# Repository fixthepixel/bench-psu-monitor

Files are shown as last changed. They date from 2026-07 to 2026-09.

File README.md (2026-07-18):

# Bench PSU Monitor

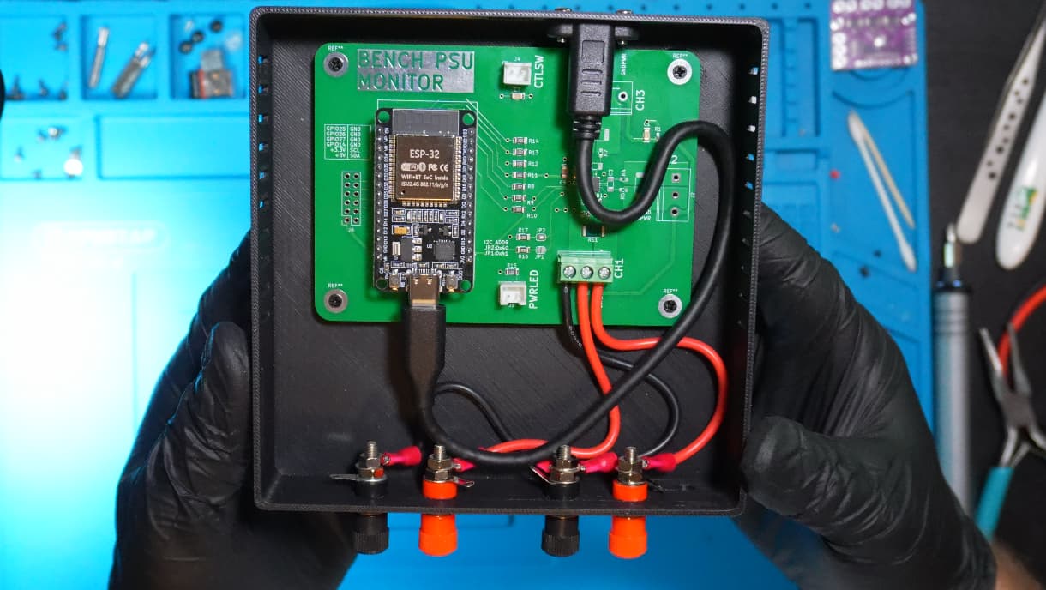
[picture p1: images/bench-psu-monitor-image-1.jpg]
Board


A 3-channel bench power supply monitor PCB built around an **ESP32 DevKit V1** and a **Texas Instruments INA3221** triple-channel current/voltage sense IC.

## Features

- 3 independent measurement channels (CH1, CH2, CH3) via screw terminals
- Voltage and current monitoring over I²C using the INA3221
- 10 mΩ shunt resistors for current sensing
- I²C address selection via solder jumpers JP1/JP2
- Compact 2-layer PCB with gerbers ready for fabrication

## Interactive BOM

[View Interactive BOM](https://fixthepixel.github.io/bench-psu-monitor/bom/ibom.html)

## Hardware

| Component | Value / Part |
|---|---|
| MCU | ESP32 DevKit V1 (30-pin) |
| Current/Voltage monitor | INA3221 (3-channel, I²C) |
| Shunt resistors | 10 mΩ (RS1, RS2, RS3) |
| Bypass capacitor | 100 nF |
| Bulk capacitor | 10 µF |

## Repository Contents

```
bench-psu-monitor.kicad_sch   Schematic
bench-psu-monitor.kicad_pcb   PCB layout
bom/ibom.html                 Interactive BOM
gerber/                       Gerber files for fabrication
firmware/                     ESP32 Arduino sketch
```

See [firmware/README.md](firmware/README.md) for flashing instructions, library dependencies, and WebSocket API reference.

## Fabrication

Gerber files are in [gerber/](gerber/) and can be sent directly to any PCB manufacturer. The board is 2-layer (F_Cu / B_Cu).

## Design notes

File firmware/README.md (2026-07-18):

# Firmware — Bench PSU Monitor

Arduino sketch for the ESP32-based bench power supply monitor. Reads voltage, current, and power from an INA3221 and streams the data over WebSocket at 10 Hz.

## Requirements

### Hardware

| Component | Detail |
|---|---|
| MCU | ESP32 DevKit V1 |
| Sensor | INA3221 at I²C address `0x40` |
| Shunt (CH1) | 10 mΩ (`SHUNT_R_CH1 = 0.01`) |
| Calibration button | GPIO0 (BOOT button) |
| WiFi button | GPIO23 |

### Libraries

Install via Arduino Library Manager or the links below:

| Library | Purpose |
|---|---|
| [Adafruit INA3221](https://github.com/adafruit/Adafruit_INA3221) | INA3221 driver |
| [WiFiManager](https://github.com/tzapu/WiFiManager) | Captive-portal WiFi setup |
| [ESPAsyncWebServer](https://github.com/me-no-dev/ESPAsyncWebServer) | Async HTTP + WebSocket server |
| [AsyncTCP](https://github.com/me-no-dev/AsyncTCP) | Async TCP layer (ESPAsyncWebServer dependency) |

`Wire.h`, `WiFi.h`, and `Preferences.h` are bundled with the ESP32 Arduino core.

### Arduino IDE Setup

1. Add the ESP32 board package URL in **File → Preferences → Additional Boards Manager URLs**:
   ```
   https://raw.githubusercontent.com/espressif/arduino-esp32/gh-pages/package_esp32_index.json
   ```
2. Install **esp32 by Espressif** via **Tools → Board → Boards Manager**.
3. Select **ESP32 Dev Module** as the target board.

## Flashing

1. Open `bench-psu-monitor.ino` in Arduino IDE.
2. Connect the ESP32 via USB.
3. Select the correct COM port under **Tools → Port**.
4. Click **Upload**.

## First-Time WiFi Configuration

On first boot (or after a reset), the device will not be connected to WiFi. Hold **GPIO23** for **3 seconds** to launch the captive-portal access point (`INA3221-Setup`). Connect to that AP from a phone or laptop, enter your WiFi credentials, and the device will save them to flash and reboot.

## Calibration

Zero-offset calibration compensates for shunt resistor and board offsets at no-load:

1. Disconnect all load from CH1.
2. Hold the **BOOT button (GPIO0)** for **2 seconds**.
3. The offset is measured and stored in NVS (survives reboots).

## WebSocket Data

Once connected to WiFi, the device hosts a WebSocket endpoint:

```
ws://<device-ip>/ws
```

JSON frames are broadcast at **100 ms intervals** (10 Hz):

```json
{"v": 12.345, "i": 123.45, "p": 1523.4, "ts": 12345678}
```

| Key | Unit | Description |
|-----|---|---|
| `v` | V | Bus voltage |
| `i` | mA | Current (zero-offset corrected) |
| `p` | mW | Power |
| `ts` | ms | `millis()` timestamp |

## Pin Summary

| GPIO | Function |
|---|---|
| 21 | I²C SDA |
| 22 | I²C SCL |
| 0 | Zero calibration (hold 2 s) |
| 23 | WiFi config portal (hold 3 s) |

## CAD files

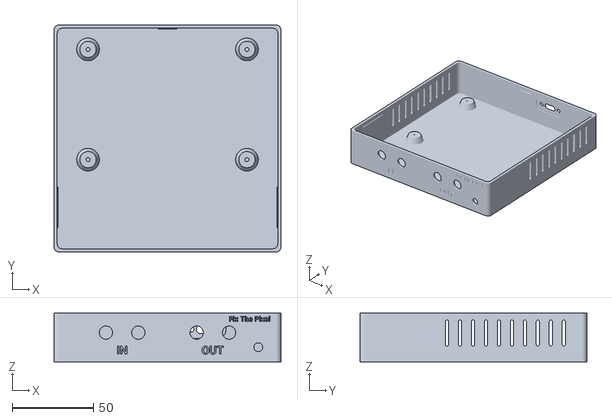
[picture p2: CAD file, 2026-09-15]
enclosure/PSU_Monitor_Enclosure.stl
140.0 x 140.0 x 30.0

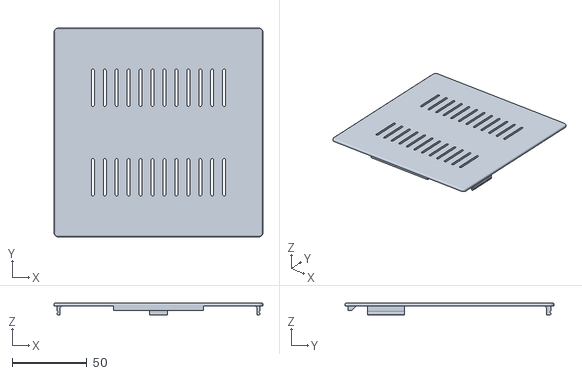
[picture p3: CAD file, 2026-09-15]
enclosure/PSU_Monitor_Lid.stl
140.0 x 140.0 x 8.00

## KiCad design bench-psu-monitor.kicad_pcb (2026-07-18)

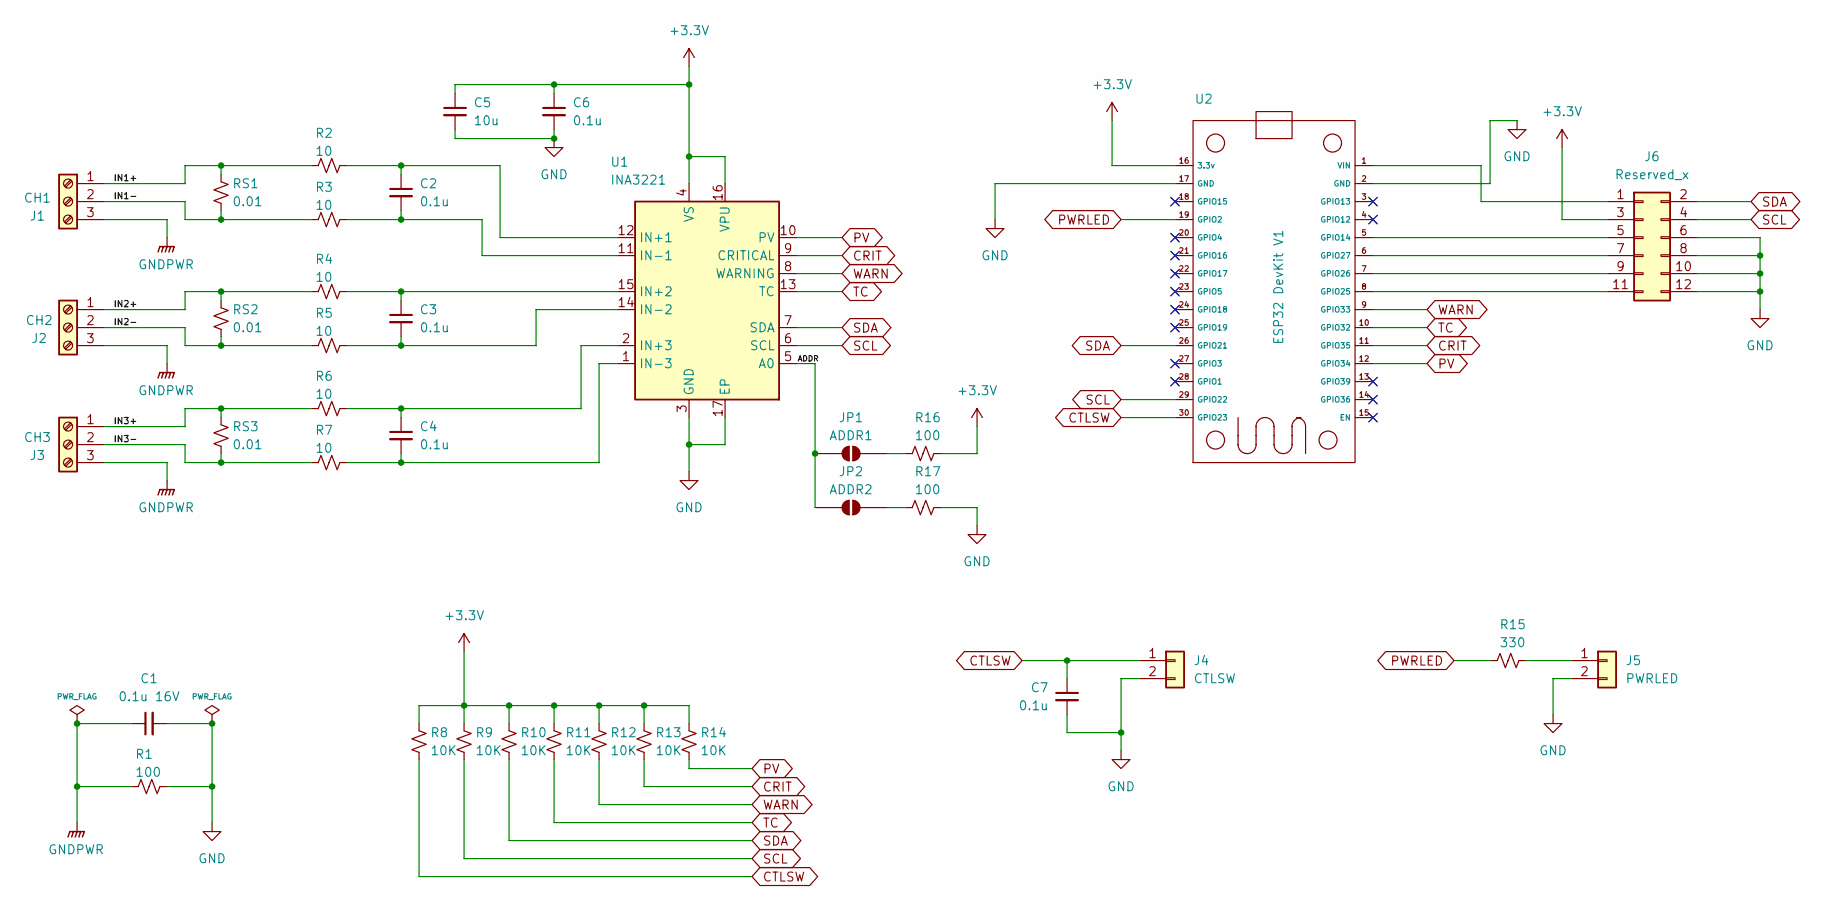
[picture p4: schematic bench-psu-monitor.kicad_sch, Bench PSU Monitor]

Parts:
C1: 0.1u 16V; C_1206_3216Metric
C2, C3, C4, C6, C7: 0.1u; C_1206_3216Metric
C5: 10u; C_1206_3216Metric
J1: CH1; TerminalBlock_Phoenix_PT-1,5-3-5.0-H_1x03_P5.00mm_Horizontal
J2: CH2; TerminalBlock_Phoenix_PT-1,5-3-5.0-H_1x03_P5.00mm_Horizontal
J3: CH3; TerminalBlock_Phoenix_PT-1,5-3-5.0-H_1x03_P5.00mm_Horizontal
J4: CTLSW; JST_XH_B2B-XH-A_1x02_P2.50mm_Vertical
J5: PWRLED; JST_XH_B2B-XH-A_1x02_P2.50mm_Vertical
J6: Reserved_x; PinSocket_2x06_P2.54mm_Vertical
JP1: ADDR1; SolderJumper-2_P1.3mm_Open_RoundedPad1.0x1.5mm
JP2: ADDR2; SolderJumper-2_P1.3mm_Open_RoundedPad1.0x1.5mm
R1: 100; R_0603_1608Metric
R2, R3, R4, R5, R6, R7: 10; R_0603_1608Metric
R8, R9, R10, R11, R12, R13, R14: 10K; R_1206_3216Metric
R15: 330; R_1206_3216Metric
R16, R17: 100; R_1206_3216Metric
RS1, RS2, RS3: 0.01; R_2512_6332Metric
U1: INA3221; Texas_RGV0016A_VQFN-16-1EP_4x4mm_P0.65mm_EP2.1x2.1mm
U2: ESP32 DevKit V1; ESP32_30pin

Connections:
+3.3V: C5.1, C6.1, J6.3, R8.1, R9.1, R10.1, R11.1, R12.1, R13.1, R14.1, R16.2, U1.4 (VS), U1.16 (VPU), U2.16 (3.3v)
/ADDR: JP1.1 (A), JP2.1 (A), U1.5 (A0)
/IN1+: J1.1, R2.1, RS1.1
/IN1-: J1.2, R3.1, RS1.2
/IN2+: J2.1, R4.1, RS2.1
/IN2-: J2.2, R5.1, RS2.2
/IN3+: J3.1, R6.1, RS3.1
/IN3-: J3.2, R7.1, RS3.2
CRIT: R13.2, U1.9 (CRITICAL), U2.11 (GPIO35)
CTLSW: C7.1, J4.1, R8.2, U2.30 (GPIO23)
GND: C1.2, C5.2, C6.2, C7.2, J4.2, J5.2, J6.6, J6.8, J6.10, J6.12, R1.2, R17.2, U1.3 (GND), U1.17 (EP), U2.2 (GND), U2.17 (GND)
GNDPWR: C1.1, J1.3, J2.3, J3.3, R1.1
unnamed: J5.1, R15.2
unnamed: J6.1, U2.1 (VIN)
unnamed: J6.5, U2.5 (GPIO14)
unnamed: J6.7, U2.6 (GPIO27)
unnamed: J6.9, U2.7 (GPIO26)
unnamed: J6.11, U2.8 (GPIO25)
unnamed: JP1.2 (B), R16.1
unnamed: JP2.2 (B), R17.1
unnamed: C2.1, R2.2, U1.12 (IN+1)
unnamed: C3.1, R4.2, U1.15 (IN+2)
unnamed: C4.1, R6.2, U1.2 (IN+3)
unnamed: C2.2, R3.2, U1.11 (IN-1)
unnamed: C3.2, R5.2, U1.14 (IN-2)
unnamed: C4.2, R7.2, U1.1 (IN-3)
PV: R14.2, U1.10 (PV), U2.12 (GPIO34)
PWRLED: R15.1, U2.19 (GPIO2)
SCL: J6.4, R9.2, U1.6 (SCL), U2.29 (GPIO22)
SDA: J6.2, R10.2, U1.7 (SDA), U2.26 (GPIO21)
TC: R11.2, U1.13 (TC), U2.10 (GPIO32)
WARN: R12.2, U1.8 (WARNING), U2.9 (GPIO33)

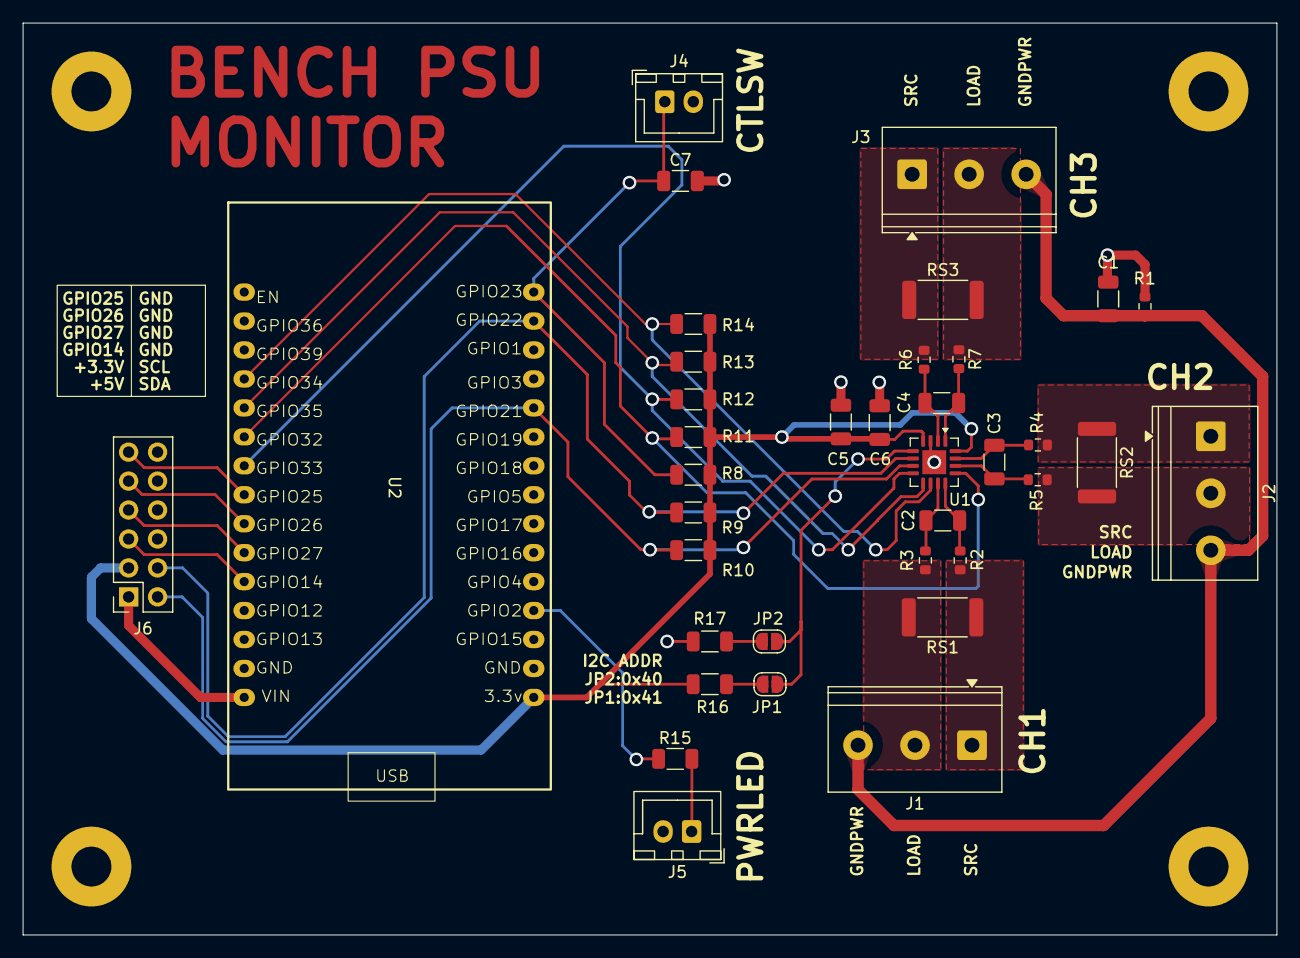
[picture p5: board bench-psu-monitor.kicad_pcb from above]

Board: 2 copper layers, 110.0 x 80.0 mm, 37 parts (0 on the bottom side), 32 nets.

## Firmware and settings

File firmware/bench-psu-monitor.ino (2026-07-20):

#include <Wire.h>
#include <Adafruit_INA3221.h>
#include <Preferences.h>
#include <WiFi.h>
#include <WiFiManager.h>
#include <ESPAsyncWebServer.h>
#include <AsyncTCP.h>

// ---------- Pins ----------
#define I2C_SDA 21
#define I2C_SCL 22
#define CAL_BUTTON_PIN 0     // BOOT button -> zero calibration
#define WIFI_BUTTON_PIN 23   // long-press -> WiFi config portal
#define PWR_LED_PIN 2
#define INA3221_ADDR 0x40
#define CH1 0

const float SHUNT_R_CH1 = 0.01;

Adafruit_INA3221 ina3221;
Preferences prefs;

AsyncWebServer server(80);   // kept only to host the /ws endpoint
AsyncWebSocket ws("/ws");

float zeroOffset_mA = 0;

unsigned long lastStream = 0;
const unsigned long STREAM_INTERVAL_MS = 100;

unsigned long calPressStart = 0;
bool calHeld = false;
const unsigned long CAL_HOLD_MS = 2000;

unsigned long wifiPressStart = 0;
bool wifiHeld = false;
const unsigned long WIFI_HOLD_MS = 3000;

static bool serverStarted = false;

void doCalibration() {
  Serial.println("Calibrating zero offset...");
  delay(200);
  zeroOffset_mA = ina3221.getCurrentAmps(CH1) * 1000.0;
  prefs.putFloat("ch1_offset", zeroOffset_mA);
  Serial.print("Saved offset: ");
  Serial.println(zeroOffset_mA);
}

void checkCalButton() {
  bool pressed = (digitalRead(CAL_BUTTON_PIN) == LOW);
  if (pressed && !calHeld) { calPressStart = millis(); calHeld = true; }
  if (pressed && calHeld && (millis() - calPressStart >= CAL_HOLD_MS)) {
    doCalibration();
    while (digitalRead(CAL_BUTTON_PIN) == LOW) delay(10);
    calHeld = false;
  }
  if (!pressed) calHeld = false;
}

void startConfigPortal() {
  Serial.println("Starting WiFi config portal (AP: INA3221-Setup)...");
  WiFiManager wm;
  wm.setConfigPortalTimeout(180);
  bool ok = wm.startConfigPortal("INA3221-Setup");
  if (ok) {
    Serial.print("WiFi connected: ");
    Serial.println(WiFi.localIP());
  } else {
    Serial.println("Config portal timed out, rebooting.");
    delay(1000);
    ESP.restart();
  }
}

void checkWifiButton() {
  bool pressed = (digitalRead(WIFI_BUTTON_PIN) == LOW);
  if (pressed && !wifiHeld) { wifiPressStart = millis(); wifiHeld = true; }
  if (pressed && wifiHeld && (millis() - wifiPressStart >= WIFI_HOLD_MS)) {
    while (digitalRead(WIFI_BUTTON_PIN) == LOW) delay(10);
    wifiHeld = false;
    startConfigPortal();
  }
  if (!pressed) wifiHeld = false;
}

void setupWebSocket() {
  ws.onEvent([](AsyncWebSocket *server, AsyncWebSocketClient *client,
                AwsEventType type, void *arg, uint8_t *data, size_t len) {
    if (type == WS_EVT_CONNECT) {
      Serial.printf("WS client connected: %u\n", client->id());
    } else if (type == WS_EVT_DISCONNECT) {
      Serial.printf("WS client disconnected: %u\n", client->id());
    }
  });
  server.addHandler(&ws);
  server.begin();
}

void setup() {
  Serial.begin(115200);
  while (!Serial) delay(10);

  pinMode(CAL_BUTTON_PIN, INPUT_PULLUP);
  pinMode(WIFI_BUTTON_PIN, INPUT_PULLUP);
  pinMode(PWR_LED_PIN, OUTPUT);

  digitalWrite(PWR_LED_PIN, LOW);

  Wire.begin(I2C_SDA, I2C_SCL);
  if (!ina3221.begin(INA3221_ADDR, &Wire)) {
    Serial.println("INA3221 not found.");
    while (1) delay(1000);
  }
  ina3221.setShuntResistance(CH1, SHUNT_R_CH1);

  prefs.begin("ina3221", false);
  zeroOffset_mA = prefs.getFloat("ch1_offset", 0.0);
  Serial.print("Loaded zero offset: ");
  Serial.println(zeroOffset_mA);

  WiFi.mode(WIFI_STA);
  WiFi.begin();
  Serial.println("Attempting saved WiFi connection...");
  unsigned long start = millis();
  while (WiFi.status() != WL_CONNECTED && millis() - start < 8000) {
    delay(250);
    Serial.print(".");
  }
  Serial.println();

  if (WiFi.status() == WL_CONNECTED) {
    Serial.print("WiFi connected: ");
    Serial.println(WiFi.localIP());
    setupWebSocket();
    serverStarted = true;
  } else {
    Serial.println("No WiFi yet. Hold GPIO23 for 3s to configure.");
  }

  Serial.println("Hold BOOT (GPIO0) 2s to calibrate zero (CH1 unloaded).");

  digitalWrite(PWR_LED_PIN, HIGH);
}

void loop() {
  checkCalButton();
  checkWifiButton();

  if (WiFi.status() == WL_CONNECTED && !serverStarted) {
    setupWebSocket();
    serverStarted = true;
    Serial.print("WS server live at ws://");
    Serial.print(WiFi.localIP());
    Serial.println("/ws");
  }

  unsigned long now = millis();
  if (WiFi.status() == WL_CONNECTED && (now - lastStream >= STREAM_INTERVAL_MS)) {
    lastStream = now;

    float busVoltage_V = ina3221.getBusVoltage(CH1);
    float rawCurrent_mA = ina3221.getCurrentAmps(CH1) * 1000.0;
    float current_mA = fabs(rawCurrent_mA - zeroOffset_mA);
    float power_mW = busVoltage_V * (current_mA / 1000.0) * 1000.0;

    char json[96];
    snprintf(json, sizeof(json),
             "{\"v\":%.3f,\"i\":%.2f,\"p\":%.1f,\"ts\":%lu}",
             busVoltage_V, current_mA, power_mW, (unsigned long)(millis()));
    ws.textAll(json);
  }

  static unsigned long lastPrint = 0;
  if (now - lastPrint >= 2000) {
    lastPrint = now;
    float busVoltage_V = ina3221.getBusVoltage(CH1);
    float current_mA = fabs(ina3221.getCurrentAmps(CH1) * 1000.0 - zeroOffset_mA);
    Serial.print(busVoltage_V, 3);
    Serial.print("V\t");
    Serial.print(current_mA, 2);
    Serial.println("mA");
  }
}

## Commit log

2026-07-18 Add kicad files with ibom and gerber files
    [bench-psu-monitor-B_Cu.gbr, bench-psu-monitor-B_Mask.gbr, bench-psu-monitor-B_Paste.gbr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]
2026-07-20 Add power LED code
2026-09-15 Add STL files for enclosure
    [PSU_Monitor_Enclosure.stl, PSU_Monitor_Lid.stl]
